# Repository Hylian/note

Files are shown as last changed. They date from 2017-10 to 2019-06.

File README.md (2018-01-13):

# TokiLabs Note

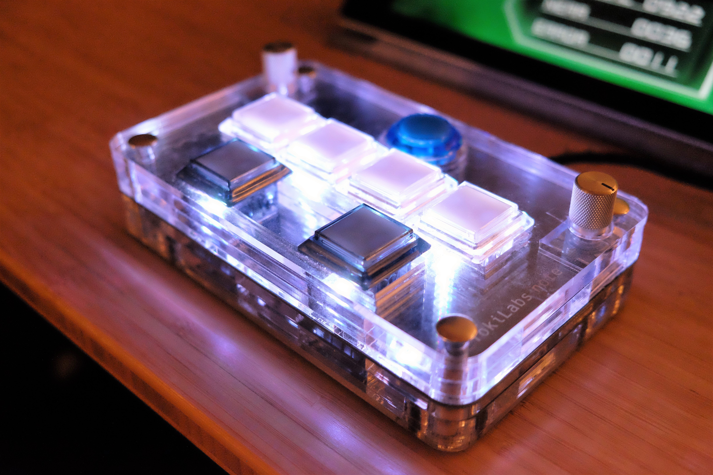
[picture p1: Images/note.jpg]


A small(er) size USB controller for the rhythm game kShootmania created with PCBmodE.

built using:

* Atmel ATmega32U4 
* Adafruit Neopixel RGB LED
* Sanwa OBSC-24KK Arcade Button
* Bourns PEC16-4020F Rotary Encoder

[Demo Video](https://www.youtube.com/watch?v=6U-hFBQ2T74)

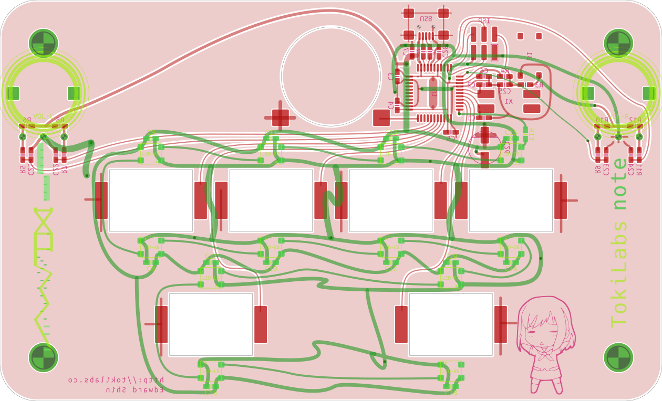
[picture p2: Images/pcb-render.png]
pcb


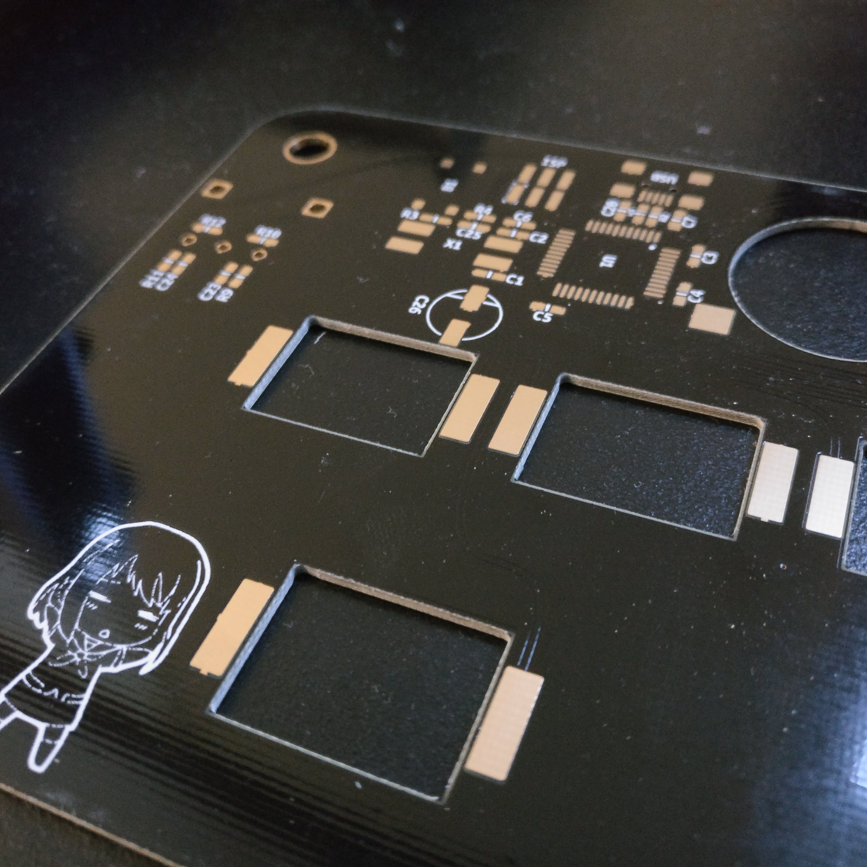
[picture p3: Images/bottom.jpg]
bottom


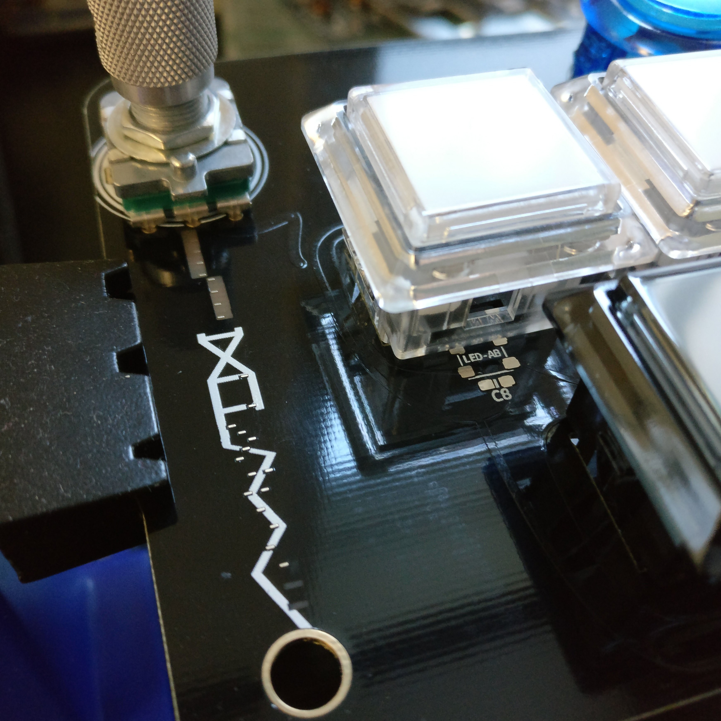
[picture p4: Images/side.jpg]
side


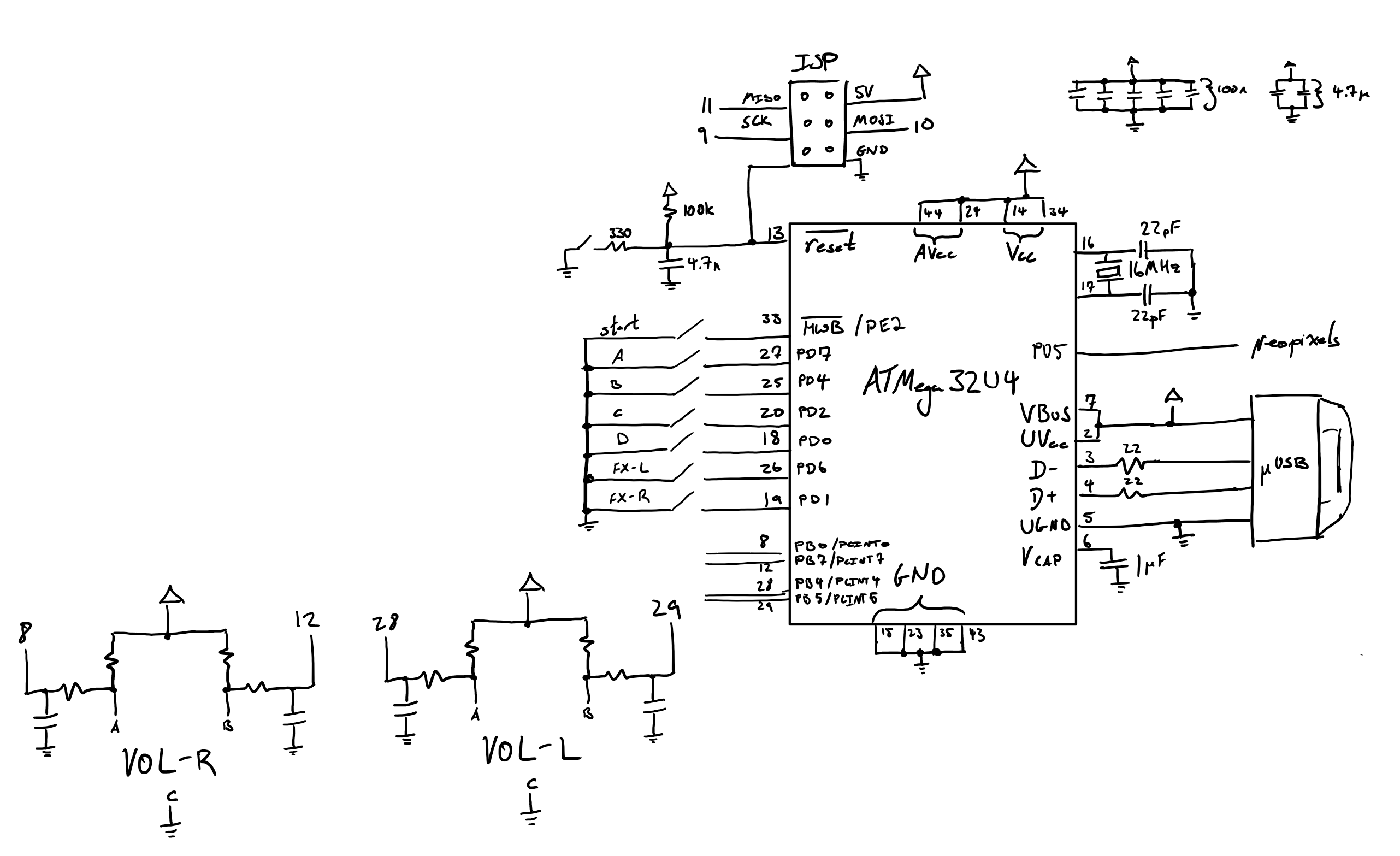
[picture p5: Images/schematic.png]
schematic


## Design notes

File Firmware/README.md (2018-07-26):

# Firmware

## Build Instructions

Update git submodules and run make. 

## Design

### Debounce

Debounce is done in the debounce.c file. It uses the Timer0 peripheral on the 32U4 to count how long a pin has been at the same level, and only exposes the level change if enough time has passed. The timer counts required to trigger a level change are configurable per-pin. Currently, there are different trigger counts configured for encoder pins and button pins.

The trigger counts are so low right now that they don't really matter. I've found that the hardware debounce on the encoders is enough.

### USB

The firmware is based off the LUFA library by Dean Camera. It instantiates three USB descriptors: an HID mouse, HID keyboard, and CDC serial for debug/configuration.

The two VOL knobs control the x/y movement of the mouse, while the buttons send keyboard button presses.

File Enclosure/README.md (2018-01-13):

# Enclosure

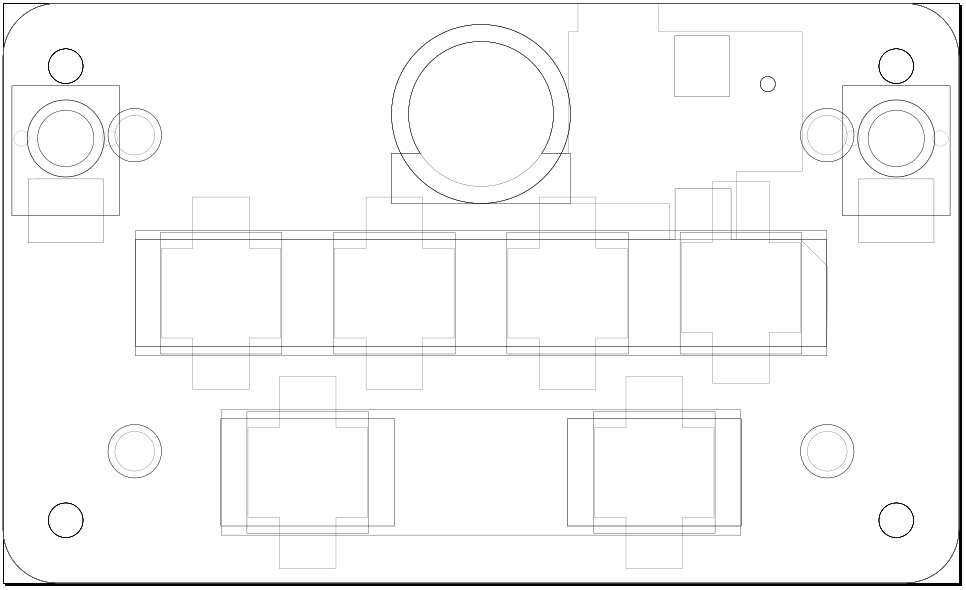
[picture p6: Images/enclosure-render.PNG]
Enclosure Render


sdvx_acrylic.svg contains the acrylic laser cut designs for the Note. Each layer is labeled with its location in the stack and thickness. The enclosure uses eight slices of acrylic in total: four 6 mm slices and four 3mm slices.

## Workflow

The primary design was done in Inkscape. However, Inkscape isn't very good at placement of multiple slices onto a sheet and .dxf export. I used Adobe Illustrator and AutoCAD to generate the final production files.

## TODO

Upload production .dxf files

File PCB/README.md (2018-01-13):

# PCB

PCB Render

## Build Instructions

Install [PCBmodE](https://github.com/boldport/pcbmode). Clone this repo into the "boards" directory within your PCBmodE installation.

### Generate the Board
```
pcbmode -b sdvx --fab -m
```
You should now be able to view the board SVG in /sdvx/build/sdvx.svg.

### Generating Gerbers
```
pcbmode -b sdvx --fab dirtypcb
```
Board files will be output to: /sdvx/build/production/

### Modifying the Design

In PCBmodE, there are two different ways to modify the design: the sdvx.json file itself, or the sdvx.svg output file in the /build/ directory.

The json can be used to define/place components, while the svg can be used to place traces and move components.

After modifying the json, regenerate the board with the -m flag. 

After modifying the svg, extract the changes with the -e flag, and then generate the board with -m.

For more info, check the [PCBmodE Wiki](http://pcbmode.readthedocs.io/en/latest/introduction.html).

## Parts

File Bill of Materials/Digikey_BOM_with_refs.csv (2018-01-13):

Digi-Key Part Number | Manufacturer | Manufacturer Part Number | Customer Reference | Quantity 1 | Quantity 2 | Quantity 3 | Mfg Std Lead Time | Description | Comments | RoHS Status | Lead Free Status | REACH Status
226-2088-ND | KILO INTERNATIONAL | OEJL-50-1-5 | KNOB | 2 | 0 | 0 | 12 Weeks | KNOB CLR GLOSS.50"DIA .250"SHAFT |  | RoHS Compliant | Lead free | Unaffected Jun-2016
WM17449-ND | MOLEX, LLC | 15912060 | ISP CONNECTOR | 1 | 0 | 0 | 8 Weeks | CONN HEADER 6POS .100" VERT TIN | Alternate Packaging Exists | RoHS Compliant | Lead free | Unaffected Jun-2015
ATMEGA32U4-AURCT-ND | MICROCHIP TECHNOLOGY (VA) | ATMEGA32U4-AUR | MCU | 1 | 0 | 0 | 12 Weeks | IC MCU 8BIT 32KB FLASH 44TQFP | Alternate Packaging Exists | RoHS Compliant | Lead free | Unaffected Jan-2017
RMCF0805JT22R0CT-ND | STACKPOLE ELECTRONICS INC (VA) | RMCF0805JT22R0 | R1, R2 - USB RESISTOR | 2 | 0 | 0 | 12 Weeks | RES SMD 22 OHM 5% 1/8W 0805 | Alternate Packaging Exists | RoHS Compliant | Lead free | Unaffected Jun-2016
311-1365-1-ND | YAGEO (VA) | CC0805KKX7R7BB105 | C20 - USB VCAP | 1 | 0 | 0 | 21 Weeks | CAP CER 1UF 16V X7R 0805 | Alternate Packaging Exists | RoHS Compliant | Lead free | Unaffected Dec-2015
399-1113-1-ND | KEMET (VA) | C0805C220J5GACTU | C1, C2 - CRYSTAL CAP | 2 | 0 | 0 | 22 Weeks | CAP CER 22PF 50V C0G/NP0 0805 | Alternate Packaging Exists | RoHS Compliant | Lead free | Unaffected Jun-2016
CKN9088CT-ND | C&K (VA) | PTS645SL50SMTR92 LFS | RESET SWITCH | 1 | 0 | 0 | 20 Weeks | SWITCH TACTILE SPST-NO 0.05A 12V | Alternate Packaging Exists | RoHS Compliant | Lead free | Unaffected Jan-2017
311-1361-1-ND | YAGEO (VA) | CC0805ZRY5V9BB104 | C3, C4, C5, C6 - POWER CAPS | 4 | 0 | 0 | 20 Weeks | CAP CER 0.1UF 50V Y5V 0805 | Alternate Packaging Exists | RoHS Compliant | Lead free | Unaffected Dec-2015
490-3335-1-ND | MURATA ELECTRONICS (VA) | GRM21BR61E475KA12L | C7 - GENERAL POWER CAP (???) | 1 | 0 | 0 | 19 Weeks | CAP CER 4.7UF 25V X5R 0805 | Alternate Packaging Exists | RoHS Compliant | Lead free | Unaffected Jun-2016
PEC16-4020F-N0024-ND | BOURNS INC | PEC16-4020F-N0024 | VOL L/R | 2 | 0 | 0 | 15 Weeks | ENCODER ROTARY 24 PULSES/REV PCB |  | RoHS Compliant | Lead free | Unaffected Jan-2017
RMCF0805JT330RCT-ND | STACKPOLE ELECTRONICS INC (VA) | RMCF0805JT330R | R4, R13 - RESET INLINE, NEOPIXEL INLINE | 2 | 0 | 0 | 12 Weeks | RES SMD 330 OHM 5% 1/8W 0805 | Alternate Packaging Exists | RoHS Compliant | Lead free | Unaffected Jun-2016
311-100KCRCT-ND | YAGEO (VA) | RC0805FR-07100KL | R3 - RESET PULLUP | 1 | 0 | 0 | 22 Weeks | RES SMD 100K OHM 1% 1/8W 0805 | Alternate Packaging Exists | RoHS Compliant | Lead free | Unaffected Dec-2015
311-10KARCT-ND | YAGEO (VA) | RC0805JR-0710KL | R5, R6, R7, R8, R9, R10, R11, R12 - ENCODER RSTR | 8 | 0 | 0 | 22 Weeks | RES SMD 10K OHM 5% 1/8W 0805 | Alternate Packaging Exists | RoHS Compliant | Lead free | Unaffected Dec-2015
399-1155-1-ND | KEMET (VA) | C0805C472K5RACTU | C25 - RESET CAP | 1 | 0 | 0 | 22 Weeks | CAP CER 4700PF 50V X7R 0805 | Alternate Packaging Exists | RoHS Compliant | Lead free | Unaffected Jun-2016
311-1361-1-ND | YAGEO (VA) | CC0805ZRY5V9BB104 | C8:C19 - LED DECOUPLING | 12 | 0 | 0 | 20 Weeks | CAP CER 0.1UF 50V Y5V 0805 | Alternate Packaging Exists | RoHS Compliant | Lead free | Unaffected Dec-2015
311-1136-1-ND | YAGEO (VA) | CC0805KRX7R9BB103 | C21, C22, C23, C24 - ENCODER CAPS | 4 | 0 | 0 | 20 Weeks | CAP CER 10000PF 50V X7R 0805 | Alternate Packaging Exists | RoHS Compliant | Lead free | Unaffected Dec-2015
311-1365-1-ND | YAGEO (VA) | CC0805KKX7R7BB105 | C20 - VCAP | 1 | 0 | 0 | 21 Weeks | CAP CER 1UF 16V X7R 0805 | Alternate Packaging Exists | RoHS Compliant | Lead free | Unaffected Dec-2015
493-2160-1-ND | NICHICON (VA) | UWT0J102MNL1GS | BIG NEOPIXEL CAP | 1 | 0 | 0 | 31 Weeks | CAP ALUM 1000UF 20% 6.3V SMD | Alternate Packaging Exists | RoHS Compliant | Lead free | Unaffected Dec-2015
1528-1104-ND | ADAFRUIT INDUSTRIES LLC | 1655 | NEOPIXELS | 2 | 0 | 0 | 5 Weeks | LED RGB WS2812 OR SK6812 1=10 |  | RoHS Compliant | Lead free | Not Available
H2959CT-ND | HIROSE ELECTRIC CO LTD (VA) | UX60-MB-5ST | USB | 1 | 0 | 0 | 8 Weeks | CONN RECEPT MINI USB2.0 5POS | Alternate Packaging Exists | RoHS Compliant | Lead free | Unaffected Dec-2014
SER2608CT-ND | EPSON (VA) | MA-506 16.0000M-C0:ROHS | CRYSTAL 4SMD | 1 | 0 | 0 | 11 Weeks | CRYSTAL 16.0000MHZ 18PF SMD | Alternate Packaging Exists | RoHS Compliant | Lead free | Not Available

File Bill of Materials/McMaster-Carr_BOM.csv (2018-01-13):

Description | Product ID | Qty
6063 Aluminum Low-Profile Binding Barrels & Screws, 8-32 Thread Size, for 1-1/4"-1-1/2" Material Thickness | 93121A350 | 4
Push-In Bumpers with Tight-Grip Stem, SBR Rubber, for 1/4" ID, 11/32" Ridge Diameter, 17/32" OD | 9309K121 | 4

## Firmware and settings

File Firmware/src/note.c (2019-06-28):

#include <avr/io.h>
#include <avr/wdt.h>
#include <avr/power.h>
#include <avr/interrupt.h>
#include <string.h>
#include <stdio.h>
#include <LUFA/Drivers/USB/USB.h>
#include <LUFA/Platform/Platform.h>
#include "descriptors.h"
#include "encoder.h"
#include "debounce.h"
#include "led.h"

/* Function Prototypes: */
void SetupHardware(void);
void SendSerial(void);

void EVENT_USB_Device_Connect(void);
void EVENT_USB_Device_Disconnect(void);
void EVENT_USB_Device_ConfigurationChanged(void);
void EVENT_USB_Device_ControlRequest(void);
void EVENT_USB_Device_StartOfFrame(void);

bool CALLBACK_HID_Device_CreateHIDReport(USB_ClassInfo_HID_Device_t* const HIDInterfaceInfo,
                                          uint8_t* const ReportID,
                                          const uint8_t ReportType,
                                          void* ReportData,
                                          uint16_t* const ReportSize);
void CALLBACK_HID_Device_ProcessHIDReport(USB_ClassInfo_HID_Device_t* const HIDInterfaceInfo,
                                          const uint8_t ReportID,
                                          const uint8_t ReportType,
                                          const void* ReportData,
                                          const uint16_t ReportSize);

/** LUFA CDC Class driver interface configuration and state information. This structure is
 *  passed to all CDC Class driver functions, so that multiple instances of the same class
 *  within a device can be differentiated from one another.
 */
USB_ClassInfo_CDC_Device_t VirtualSerial_CDC_Interface =
  {
    .Config =
      {
        .ControlInterfaceNumber   = INTERFACE_ID_CDC_CCI,
        .DataINEndpoint           =
          {
            .Address          = CDC_TX_EPADDR,
            .Size             = CDC_TXRX_EPSIZE,
            .Banks            = 1,
          },
        .DataOUTEndpoint =
          {
            .Address          = CDC_RX_EPADDR,
            .Size             = CDC_TXRX_EPSIZE,
            .Banks            = 1,
          },
        .NotificationEndpoint =
          {
            .Address          = CDC_NOTIFICATION_EPADDR,
            .Size             = CDC_NOTIFICATION_EPSIZE,
            .Banks            = 1,
          },
      },
  };

/** Standard file stream for the CDC interface when set up, so that the virtual CDC COM port can be
 *  used like any regular character stream in the C APIs.
 */
static FILE USBSerialStream;

/** Buffer to hold the previously generated Keyboard HID report, for comparison purposes inside the HID class driver. */
static uint8_t PrevKeyboardHIDReportBuffer[sizeof(USB_KeyboardReport_Data_t)];

/** Buffer to hold the previously generated Mouse HID report, for comparison purposes inside the HID class driver. */
static uint8_t PrevMouseHIDReportBuffer[sizeof(USB_MouseReport_Data_t)];

/** LUFA HID Class driver interface configuration and state information. This structure is
 *  passed to all HID Class driver functions, so that multiple instances of the same class
 *  within a device can be differentiated from one another. This is for the keyboard HID
 *  interface within the device.
 */
USB_ClassInfo_HID_Device_t Keyboard_HID_Interface =
  {
    .Config =
      {
        .InterfaceNumber              = INTERFACE_ID_Keyboard,
        .ReportINEndpoint             =
          {
            .Address              = KEYBOARD_IN_EPADDR,
            .Size                 = HID_EPSIZE,
            .Banks                = 1,
          },
        .PrevReportINBuffer           = PrevKeyboardHIDReportBuffer,
        .PrevReportINBufferSize       = sizeof(PrevKeyboardHIDReportBuffer),
      },
  };

/** LUFA HID Class driver interface configuration and state information. This structure is
 *  passed to all HID Class driver functions, so that multiple instances of the same class
 *  within a device can be differentiated from one another.
 */
USB_ClassInfo_HID_Device_t Mouse_HID_Interface =
  {
    .Config =
      {
        .InterfaceNumber                = INTERFACE_ID_Mouse,
        .ReportINEndpoint               =
          {
            .Address                = MOUSE_IN_EPADDR,
            .Size                   = HID_EPSIZE,
            .Banks                  = 1,
          },
        .PrevReportINBuffer             = PrevMouseHIDReportBuffer,
        .PrevReportINBufferSize         = sizeof(PrevMouseHIDReportBuffer),
      },
  };

/** Configures the board hardware and chip peripherals for the demo's functionality. */
void SetupHardware(void)
{
  /* Disable watchdog if enabled by bootloader/fuses */
  MCUSR &= ~(1 << WDRF);
  wdt_disable();

  /* Disable clock division */
  clock_prescale_set(clock_div_1);

  /* Configure all button pins to use internal pullup */
  PORTD |= (1<<7) | (1<<4) | (1<<2) | (1<<0) | (1<<6) | (1<<1);
  PORTE |= (1<<2);
  PORTB |= (1<<0) | (1<<4) | (1<<5) | (1<<7);

  /* Subsystem Initialization */
  EncoderInit();
  DebounceInit();
  LedInit();

  USB_Init();
}

/** Main program entry point. This routine contains the overall program flow, including initial
 *  setup of all components and the main program loop.
 */

uint16_t count = 0;

int main(void)
{
  SetupHardware();

  /* Create a regular character stream for the interface so that it can be used with the stdio.h functions */
  CDC_Device_CreateStream(&VirtualSerial_CDC_Interface, &USBSerialStream);

  GlobalInterruptEnable();

  while(1)
  {
    DebounceUpdate();
    EncoderUpdate();
    LedUpdate();

    SendSerial();

    /* Must throw away unused bytes from the host, or it will lock up while waiting for the device */
    CDC_Device_ReceiveByte(&VirtualSerial_CDC_Interface);

    CDC_Device_USBTask(&VirtualSerial_CDC_Interface);
    HID_Device_USBTask(&Mouse_HID_Interface);
    HID_Device_USBTask(&Keyboard_HID_Interface);

    USB_USBTask();
  }
}

/** Send debug information over serial */
void SendSerial(void)
{
  char ReportString[70];
  /*
  uint8_t leftdelta = EncoderGetLeftDelta();
  uint8_t rightdelta = EncoderGetRightDelta();

  if (leftdelta || rightdelta) {
    sprintf(ReportString, "Left: %i, Right: %i ", leftdelta, rightdelta);
    fputs(ReportString, &USBSerialStream);
  }
  */

  //sprintf(ReportString, "Debounce Stats: avg(%u) min(%u) max(%u) 4us counts\r\n", debounce_stats.avg, debounce_stats.min, debounce_stats.max);
  //fputs(ReportString, &USBSerialStream);

  /* Alternatively, without the stream: */
  // CDC_Device_SendString(&VirtualSerial_CDC_Interface, ReportString);
}

/** Event handler for the library USB Connection event. */
void EVENT_USB_Device_Connect(void)
{
}

/** Event handler for the library USB Disconnection event. */
void EVENT_USB_Device_Disconnect(void)
{
}

/** Event handler for the library USB Configuration Changed event. */
void EVENT_USB_Device_ConfigurationChanged(void)
{
  bool ConfigSuccess = true;

  ConfigSuccess &= HID_Device_ConfigureEndpoints(&Keyboard_HID_Interface);
  ConfigSuccess &= HID_Device_ConfigureEndpoints(&Mouse_HID_Interface);
  ConfigSuccess &= CDC_Device_ConfigureEndpoints(&VirtualSerial_CDC_Interface);

  USB_Device_EnableSOFEvents();
}

/** Event handler for the library USB Control Request reception event. */
void EVENT_USB_Device_ControlRequest(void)
{
  HID_Device_ProcessControlRequest(&Keyboard_HID_Interface);
  HID_Device_ProcessControlRequest(&Mouse_HID_Interface);
  CDC_Device_ProcessControlRequest(&VirtualSerial_CDC_Interface);
}

/** Event handler for the USB device Start Of Frame event. */
void EVENT_USB_Device_StartOfFrame(void)
{
  HID_Device_MillisecondElapsed(&Keyboard_HID_Interface);
  HID_Device_MillisecondElapsed(&Mouse_HID_Interface);
}

/** HID class driver callback function for the creation of HID reports to the host.
 *
 *  \param[in]     HIDInterfaceInfo  Pointer to the HID class interface configuration structure being referenced
 *  \param[in,out] ReportID    Report ID requested by the host if non-zero, otherwise callback should set to the generated report ID
 *  \param[in]     ReportType  Type of the report to create, either HID_REPORT_ITEM_In or HID_REPORT_ITEM_Feature
 *  \param[out]    ReportData  Pointer to a buffer where the created report should be stored
 *  \param[out]    ReportSize  Number of bytes written in the report (or zero if no report is to be sent)
 *  \return Boolean \c true to force the sending of the report, \c false to let the library determine if it needs to be sent
 */
bool CALLBACK_HID_Device_CreateHIDReport(USB_ClassInfo_HID_Device_t* const HIDInterfaceInfo,
                                         uint8_t* const ReportID,
                                         const uint8_t ReportType,
                                         void* ReportData,
                                         uint16_t* const ReportSize)
{
  if (HIDInterfaceInfo == &Keyboard_HID_Interface) {
    USB_KeyboardReport_Data_t* KeyboardReport = (USB_KeyboardReport_Data_t*)ReportData;

    //KeyboardReport->Modifier = HID_KEYBOARD_MODIFIER_LEFTSHIFT;
    if (!DebounceGetLevel(BT_A)) {
      KeyboardReport->KeyCode[0] = HID_KEYBOARD_SC_S;
    }
    if (!DebounceGetLevel(BT_B)) {
      KeyboardReport->KeyCode[1] = HID_KEYBOARD_SC_D;
    }
    if (!DebounceGetLevel(BT_C)) {
      KeyboardReport->KeyCode[2] = HID_KEYBOARD_SC_K;
    }
    if (!DebounceGetLevel(BT_D)) {
      KeyboardReport->KeyCode[3] = HID_KEYBOARD_SC_L;
    }
    if (!DebounceGetLevel(FX_L)) {
      KeyboardReport->KeyCode[4] = HID_KEYBOARD_SC_V;
    }
    if (!DebounceGetLevel(FX_R)) {
      KeyboardReport->KeyCode[5] = HID_KEYBOARD_SC_M;
    }
    if (!DebounceGetLevel(START)) {
      KeyboardReport->KeyCode[0] = HID_KEYBOARD_SC_ENTER;
    }

    *ReportSize = sizeof(USB_KeyboardReport_Data_t);
    return false;
  } else {
    USB_MouseReport_Data_t* MouseReport = (USB_MouseReport_Data_t*)ReportData;

    MouseReport->Y = -1*EncoderGetRightDelta();
    MouseReport->X = 1*EncoderGetLeftDelta();

    EncoderResetLeftDelta();
    EncoderResetRightDelta();

    *ReportSize = sizeof(USB_MouseReport_Data_t);
    return true;
  }
  return false;
}

/** HID class driver callback function for the processing of HID reports from the host.
 *
 *  \param[in] HIDInterfaceInfo  Pointer to the HID class interface configuration structure being referenced
 *  \param[in] ReportID    Report ID of the received report from the host
 *  \param[in] ReportType  The type of report that the host has sent, either HID_REPORT_ITEM_Out or HID_REPORT_ITEM_Feature
 *  \param[in] ReportData  Pointer to a buffer where the received report has been stored
 *  \param[in] ReportSize  Size in bytes of the received HID report
 */
void CALLBACK_HID_Device_ProcessHIDReport(USB_ClassInfo_HID_Device_t* const HIDInterfaceInfo,
                                          const uint8_t ReportID,
                                          const uint8_t ReportType,
                                          const void* ReportData,
                                          const uint16_t ReportSize)
{
  // Unused (but mandatory for the HID class driver) in this demo, since there are no Host->Device reports
}

/** CDC class driver callback function the processing of changes to the virtual
 *  control lines sent from the host..
 *
 *  \param[in] CDCInterfaceInfo  Pointer to the CDC class interface configuration structure being referenced
 */
void EVENT_CDC_Device_ControLineStateChanged(USB_ClassInfo_CDC_Device_t *const CDCInterfaceInfo)
{
  /* You can get changes to the virtual CDC lines in this callback; a common
     use-case is to use the Data Terminal Ready (DTR) flag to enable and
     disable CDC communications in your application when set to avoid the
     application blocking while waiting for a host to become ready and read
     in the pending data from the USB endpoints.
  */
  //bool HostReady = (CDCInterfaceInfo->State.ControlLineStates.HostToDevice & CDC_CONTROL_LINE_OUT_DTR) != 0;
}

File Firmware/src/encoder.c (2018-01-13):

#include "encoder.h"

#include <avr/io.h>
#include <stdint.h>
#include <stdbool.h>

#include "debounce.h"

static uint8_t old_AB_left = 0;
static uint8_t old_AB_right = 0;
static const int8_t enc_states[] = {0,-1,1,0,1,0,0,-1,-1,0,0,1,0,1,-1,0};
static int8_t delta_left = 0;
static int8_t delta_right = 0;

void EncoderInit(void)
{
  DDRB = 0x0;
}
  
void EncoderUpdate(void)
{
  bool new_A_left = DebounceGetLevel(ENC_LEFT_A);
  bool new_B_left = DebounceGetLevel(ENC_LEFT_B);
  bool new_A_right = DebounceGetLevel(ENC_RIGHT_A);
  bool new_B_right = DebounceGetLevel(ENC_RIGHT_B);

  old_AB_left <<= 2;
  old_AB_left |= (uint8_t) ( (new_A_left << 1) | new_B_left );
  
  old_AB_right <<= 2;
  old_AB_right |= (uint8_t) ( (new_A_right << 1) | new_B_right );
  
  if (delta_left > -126 && delta_left < 127) {
    delta_left += enc_states[( old_AB_left & 0x0f )];
  }    
  if (delta_right > -126 && delta_right < 127) {
    delta_right += enc_states[( old_AB_right & 0x0f )];
  }    
}

int8_t EncoderGetLeftDelta(void)
{
  return delta_left;
}

void EncoderResetLeftDelta(void)
{
  delta_left = 0;
}

int8_t EncoderGetRightDelta(void)
{
  return delta_right;
}

void EncoderResetRightDelta(void)
{
  delta_right = 0;
}

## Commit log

2016-08-20 tqfp44 footprint test
2016-10-14 modified decopuling caps and added filtering to rotary encoders
2016-10-14 add documentation to board
2016-10-18 Fix encoder filter labeling
2016-10-19 change start button to round button
2016-10-20 lots of minor routing changes, added switch pins to encoders
2016-10-25 switch from micro usb to mini usb
2016-11-02 change encoder to pec12r
2016-11-16 add ground pour to bottom layer
2016-11-18 modified traces for bottom ground pour
2016-12-08 routing changes for ground pour
2017-01-22 board outline with cutouts
2017-01-27 add mounting holes
2017-01-27 increase width of ground trace
2017-01-30 add ground stitch vias
2017-03-27 remove stripes, add sdvx map decals
    [sdvx_rev_first_bottom_conductor.GBL, sdvx_rev_first_bottom_silkscreen.GBO, sdvx_rev_first_bottom_soldermask.GBS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]
2017-04-04 Add new decals and title
    [sdvx_rev_first_top_conductor.GTL, sdvx_rev_first_top_silkscreen.GTO, sdvx_rev_first_top_soldermask.GTS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]
2017-04-04 Cosmetic fixups
    [sdvx_rev_first_bottom_conductor.GBL, sdvx_rev_first_bottom_silkscreen.GBO, sdvx_rev_first_bottom_solderpaste.GBP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]
2017-04-04 Add toki logo
    [sdvx_rev_first_bottom_silkscreen.GBO, sdvx_rev_first_top_silkscreen.GTO]
2017-04-07 Update to use pec16
    [sdvx_rev_first_bottom_silkscreen.gbo, sdvx_rev_first_bottom_soldermask.gbs, sdvx_rev_first_bottom_solderpaste.gbp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]
2017-04-07 widen some power traces
2017-04-08 better power routing and add big fat nichicon cap
2017-04-09 implement gerber_lp
2018-01-13 Put everything in one repo
    [Digikey_BOM_with_refs.csv, McMaster-Carr_BOM.csv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]
2018-01-13 Update enclosure README
2018-07-28 Remove extra serial driver file
2018-07-28 Add production gerbers
    [sdvx_rev_first_bottom_conductor.GBL, sdvx_rev_first_bottom_conductor.gbl, sdvx_rev_first_bottom_silkscreen.gbo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]
